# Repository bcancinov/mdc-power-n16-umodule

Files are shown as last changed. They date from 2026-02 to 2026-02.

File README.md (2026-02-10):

# mdc-power-n16-umodule
Modular Detector Controller Power -16V uModule Mezzanine Module

## Overview
12V input to -16V output DC-DC module, 0.5A nominal output, used as one of the `mdc-power-*` bias rails.
Designed for 2 MHz sync operation.
Mezzanine module.

## Power Stage
- Controller: `LTM4651` (uModule)
  - Integrated µModule regulator including controller, MOSFETs, inductor, and support components.
  - EN55022B compliant regulator family (meets Class B EMI limits for conducted and radiated emissions).
  - External sync capability.

## Files
- Schematic: `power_n16_umodule.pdf`

## Board Dimensions
- 44.8 mm x 41.5 mm

## Board Stackup
- 4-layer PCB

## CAD
- Designed using KiCad 9.

## Interface
- Control pins: `EN` (enable) and `PG` / `~PGOOD` (power good).
- Connector: `LSHM-140-04.0-L-DV-A-N-K-TR` (Samtec LSHM series) mezzanine for power and control signals.
  - Common pinout is shared across the 16V, -16V, 6V, and 3.3V variants.
  - Unused output rails are tied to GND on the specific module variant.

## Images
Layout:
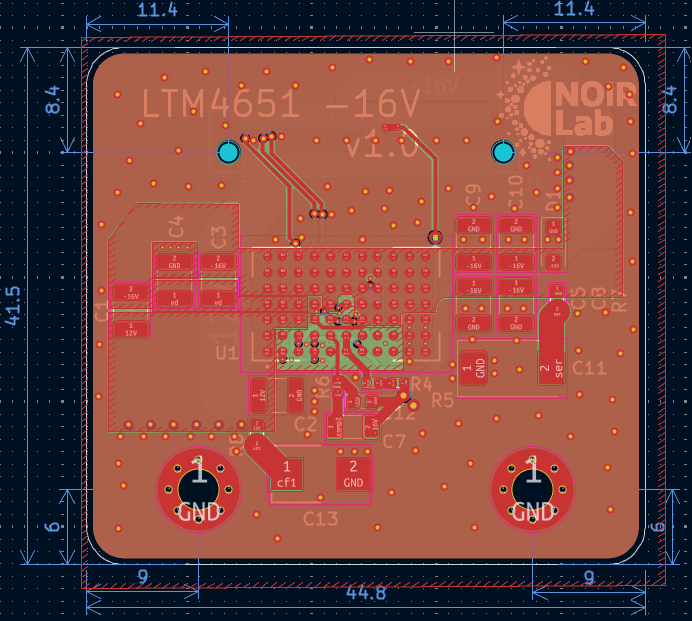
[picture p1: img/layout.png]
Layout


3D view:
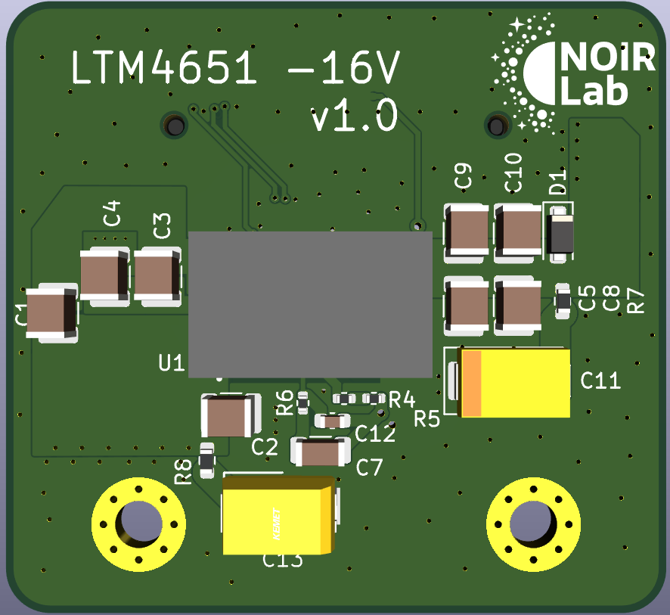
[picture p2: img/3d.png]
3D view


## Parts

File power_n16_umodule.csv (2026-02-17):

Reference | Qty | MPN | M | Description
C1,C2,C3,C4 | 4 | GRM32ER71K475KE14L | Murata | 4.7 µF ±10% 80V Ceramic Capacitor X7R 1210 (3225 Metric)
C5,C8,C9,C10 | 4 | TMK325ABJ476MM-P | TAIYO YUDEN | 47 µF ±20% 25V Ceramic Capacitor X5R 1210 (3225 Metric)
C6 | 1 | GCM21BR71H105KA03L | Murata | 1 µF ±10% 50V Ceramic Capacitor X7R 0805 (2012 Metric)
C7 | 1 | GCM31M5C1H473FA16L | Murata | 0.047 µF ±1% 50V Ceramic Capacitor C0G, NP0 1206 (3216 Metric)
C11 | 1 | T521V226M025ATE040 | KEMET | 22 µF Molded Tantalum Polymer Capacitor 25 V 2917 (7343 Metric) 40mOhm @ 100kHz
C12 | 1 | GCM1885C2A100FA16D | Murata | 10 pF ±1% 100V Ceramic Capacitor C0G, NP0 0603 (1608 Metric)
C13 | 1 | T521X107M025ATE060 | Kemet | 100 µF Molded Tantalum Polymer Capacitor 25 V 2917 (7343 Metric) 60mOhm @ 100kHz
D1 | 1 | CMMSH1-40L TR PBFREE | Central Semiconductor Corp | Diode 40 V 1A Surface Mount SOD-123F
H1,H2,NT1 | 3 |  |  | Mounting Hole with connection,Net tie, 2 pins
J1 | 1 | LSHM-140-04.0-L-DV-A-N-K-TR | Samtec | 80 Position Connector Self Mating, Non-Gendered, Hermaphroditic Surface Mount Gold
R1 | 1 | CRCW040262K0FKED | Vishay | 62 kOhms ±1% 0.063W, 1/16W Chip Resistor 0402 (1005 Metric) Automotive AEC-Q200 Thick Film
R2 | 1 | CRCW0402127KFKEDC | Vishay | 127 kOhms ±1% 0.063W, 1/16W Chip Resistor 0402 (1005 Metric) Thick Film
R3 | 1 | CRCW040268R0FKEDHP | Vishay | 68 Ohms ±1% 0.2W, 1/5W Chip Resistor 0402 (1005 Metric) Automotive AEC-Q200, Pulse Withstanding Thick Film
R4 | 1 | CRCW0402316KFKED | Vishay | 316 kOhms ±1% 0.063W, 1/16W Chip Resistor 0402 (1005 Metric) Automotive AEC-Q200 Thick Film
R5 | 1 | CRCW04024K02FKED | Vishay | 4.02 kOhms ±1% 0.063W, 1/16W Chip Resistor 0402 (1005 Metric) Automotive AEC-Q200 Thick Film
R6 | 1 | CRCW04023K48FKED | Vishay | 3.48 kOhms ±1% 0.1W, 1/10W Chip Resistor 0402 (1005 Metric) Automotive AEC-Q200 Thick Film
R7,R8 | 2 | RCWE0603R500FKEA | Vishay | 500 mOhms ±1% 0.2W, 1/5W Chip Resistor 0603 (1608 Metric) Automotive AEC-Q200, Current Sense, Moisture Resistant Thick Film
U1 | 1 | LTM4651EY#PBF | Analog Devices | Non-Isolated PoL Module DC DC Converter 1 Output -0.5 ~ -26.5V 3.6V - 58V Input

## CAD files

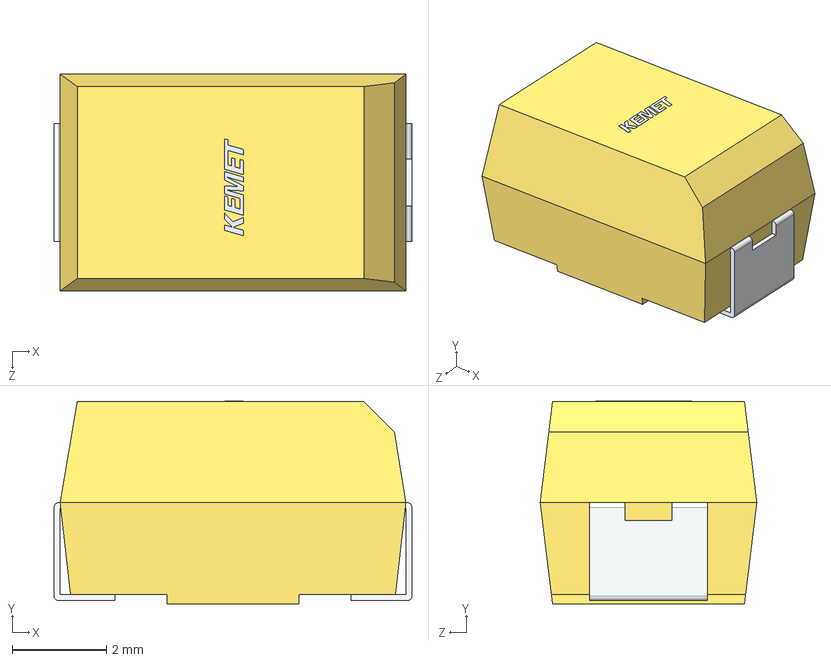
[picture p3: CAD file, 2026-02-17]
step/T521X.step
7.60 x 4.30 x 4.60 mm

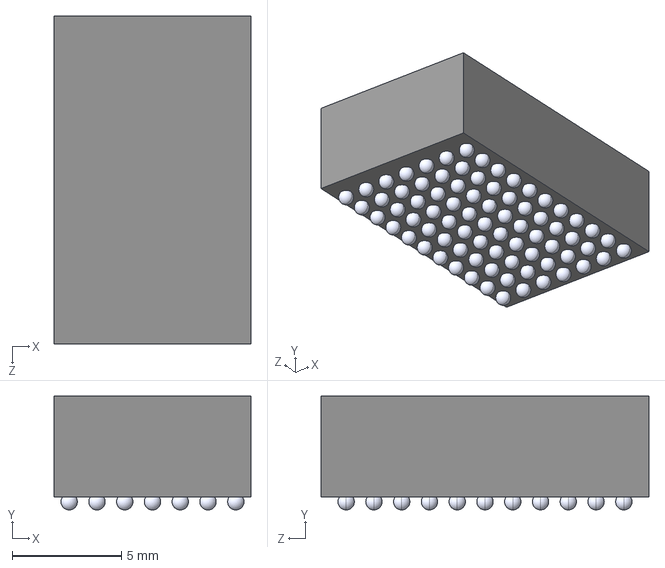
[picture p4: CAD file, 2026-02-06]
step/LTM4651EY_PBF.step
9.00 x 5.21 x 15.0 mm

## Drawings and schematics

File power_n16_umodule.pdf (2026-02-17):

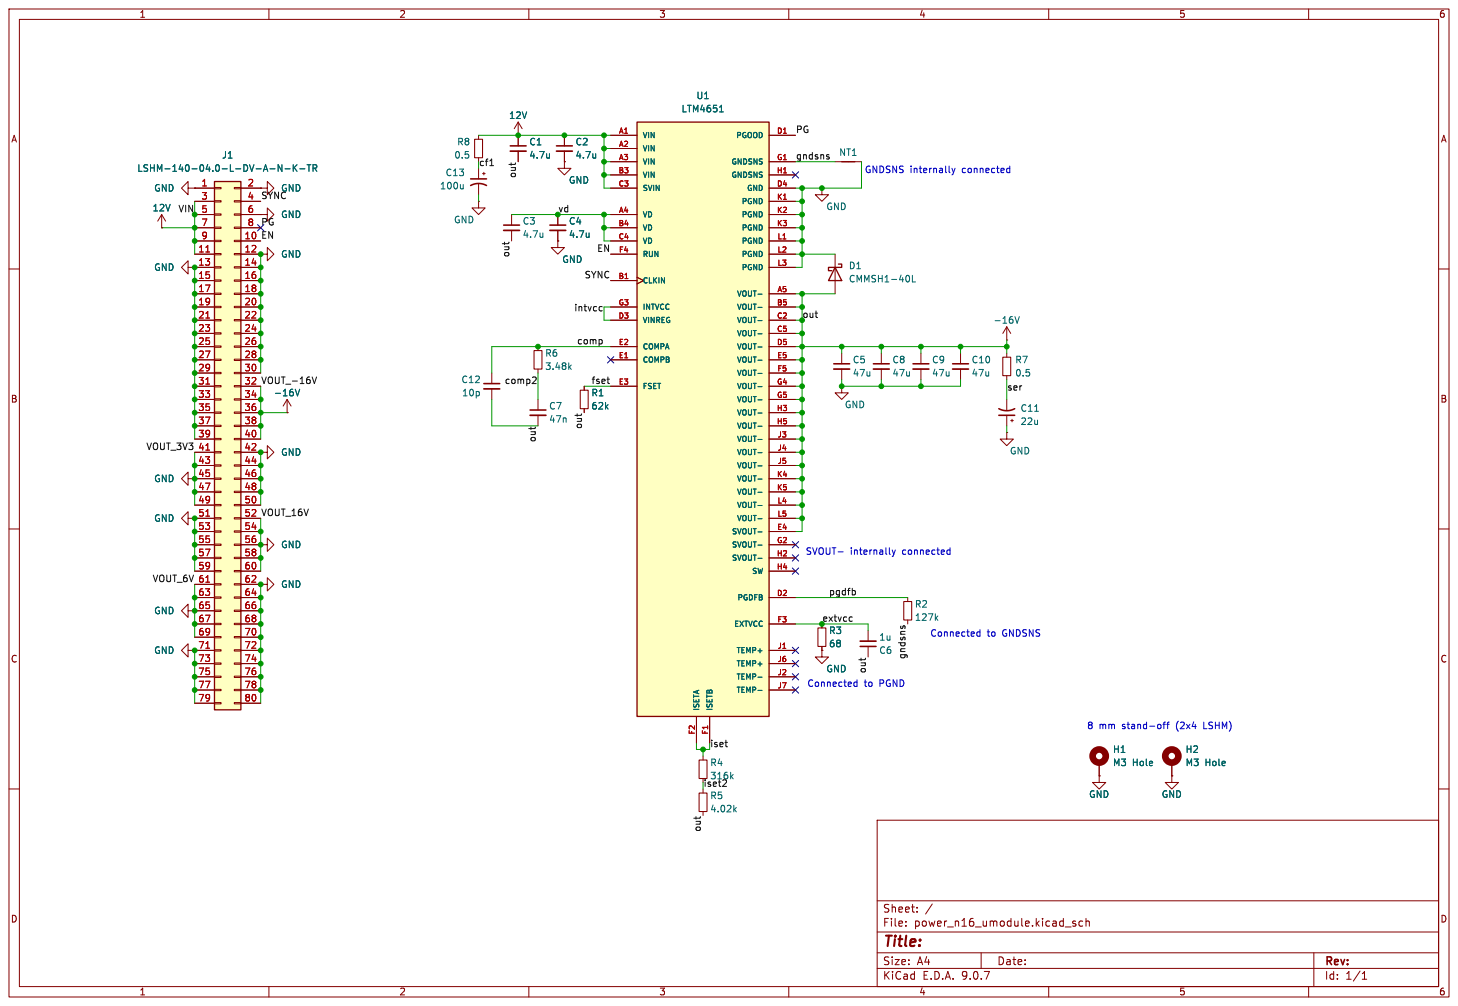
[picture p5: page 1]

LSHM-140-04.0-L-DV-A-N-K-TR GND GND
-16V GND GND
VIN

Id: 1/1 Title: File: power_n16_umodule.kicad_sch Sheet: /

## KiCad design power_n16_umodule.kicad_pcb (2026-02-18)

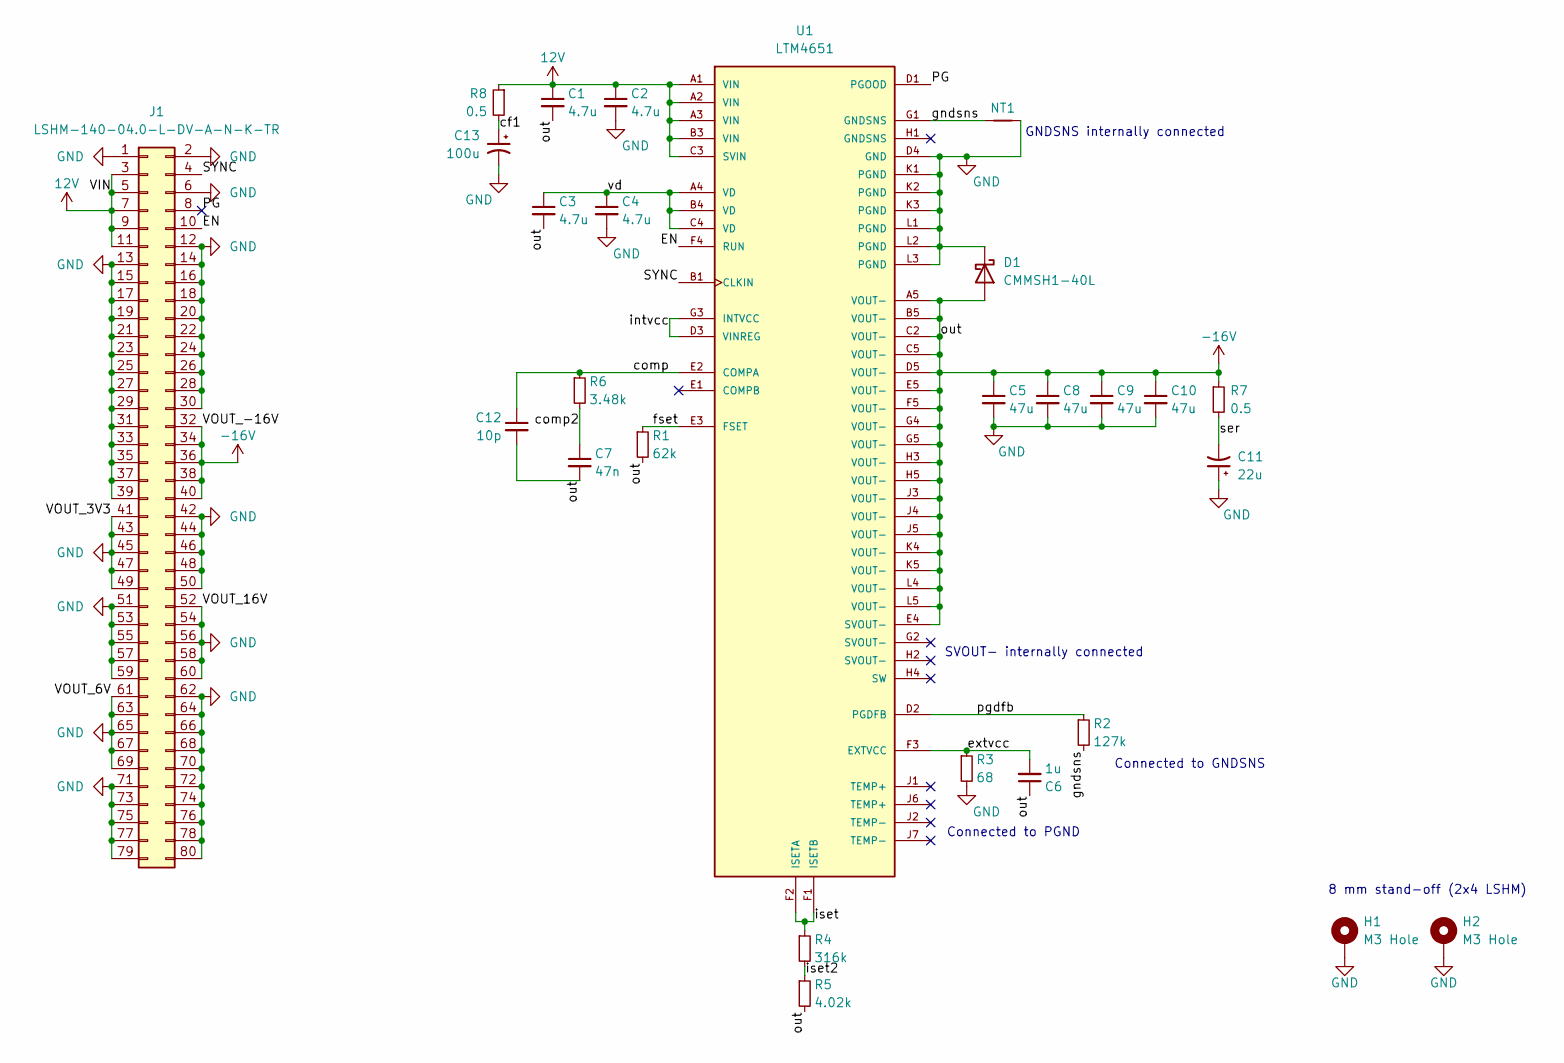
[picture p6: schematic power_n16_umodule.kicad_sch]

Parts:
C1, C2, C3, C4: 4.7u; C_1210_3225Metric; MPN GRM32ER71K475KE14L
C5, C8, C9, C10: 47u; C_1210_3225Metric; MPN TMK325ABJ476MM-P
C6: 1u; C_0805_2012Metric; MPN GCM21BR71H105KA03L
C7: 47n; C_1206_3216Metric; MPN GCM31M5C1H473FA16L
C11: 22u; CP_EIA-7343-20_Kemet-V; MPN T521V226M025ATE040
C12: 10p; C_0603_1608Metric; MPN GCM1885C2A100FA16D
C13: 100u; T521X; MPN T521X107M025ATE060
D1: CMMSH1-40L; D_SOD-123F; MPN CMMSH1-40L TR PBFREE
H1, H2: M3 Hole; MountingHole_3.2mm_M3_Pad_Via
J1: LSHM-140-04.0-L-DV-A-N-K-TR; SAMTEC_LSHM-140-04.0-L-DV-A-N-K-TR; MPN LSHM-140-04.0-L-DV-A-N-K-TR
NT1: NetTie-2_SMD_Pad0.5mm
R1: 62k; R_0402_1005Metric; MPN CRCW040262K0FKED
R2: 127k; R_0402_1005Metric; MPN CRCW0402127KFKEDC
R3: 68; R_0402_1005Metric; MPN CRCW040268R0FKEDHP
R4: 316k; R_0402_1005Metric; MPN CRCW0402316KFKED
R5: 4.02k; R_0402_1005Metric; MPN CRCW04024K02FKED
R6: 3.48k; R_0402_1005Metric; MPN CRCW04023K48FKED
R7, R8: 0.5; R_0603_1608Metric; MPN RCWE0603R500FKEA
U1: LTM4651; MPN LTM4651EY#PBF

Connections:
12V: C1.1, C2.1, J1.3, J1.5, J1.7, J1.9, J1.11, R8.1, U1.A1 (VIN), U1.A2 (VIN), U1.A3 (VIN), U1.B3 (VIN), U1.C3 (SVIN)
-16V: C1.2, C3.2, C5.1, C6.1, C7.2, C8.1, C9.1, C10.1, C12.2, D1.2 (A), J1.32, J1.34, J1.36, J1.38, J1.40, R1.2, R5.2, R7.1, U1.A5 (VOUT-), U1.B5 (VOUT-), U1.C2 (VOUT-), U1.C5 (VOUT-), U1.D5 (VOUT-), U1.E4 (SVOUT-), U1.E5 (VOUT-), U1.F5 (VOUT-), U1.G4 (VOUT-), U1.G5 (VOUT-), U1.H3 (VOUT-), U1.H5 (VOUT-), U1.J3 (VOUT-), U1.J4 (VOUT-), U1.J5 (VOUT-), U1.K4 (VOUT-), U1.K5 (VOUT-), U1.L4 (VOUT-), U1.L5 (VOUT-)
/EN: J1.10, U1.F4 (RUN)
/PG: J1.8, U1.D1 (PGOOD)
/SYNC: J1.4, U1.B1 (CLKIN)
/cf1: C13.1, R8.2
/comp: C12.1, R6.1, U1.E2 (COMPA)
/comp2: C7.1, R6.2
/extvcc: C6.2, R3.1, U1.F3 (EXTVCC)
/fset: R1.1, U1.E3 (FSET)
/gndsns: NT1.1, R2.2, U1.G1 (GNDSNS)
/intvcc: U1.D3 (VINREG), U1.G3 (INTVCC)
/iset: R4.1, U1.F1 (ISETB), U1.F2 (ISETA)
/iset2: R4.2, R5.1
/pgdfb: R2.1, U1.D2 (PGDFB)
/ser: C11.2, R7.2
/vd: C3.1, C4.1, U1.A4 (VD), U1.B4 (VD), U1.C4 (VD)
GND: C2.2, C4.2, C5.2, C8.2, C9.2, C10.2, C11.1, C13.2, D1.1 (K), H1.1, H2.1, J1.1, J1.2, J1.6, J1.12, J1.13, J1.14, J1.15, J1.16, J1.17, J1.18, J1.19, J1.20, J1.21, J1.22, J1.23, J1.24, J1.25, J1.26, J1.27, J1.28, J1.29, J1.30, J1.31, J1.33, J1.35, J1.37, J1.39, J1.41, J1.42, J1.43, J1.44, J1.45, J1.46, J1.47, J1.48, J1.49, J1.50, J1.51, J1.52, J1.53, J1.54, J1.55, J1.56, J1.57, J1.58, J1.59, J1.60, J1.61, J1.62, J1.63, J1.64, J1.65, J1.66, J1.67, J1.68, J1.69, J1.70, J1.71, J1.72, J1.73, J1.74, J1.75, J1.76, J1.77, J1.78, J1.79, J1.80, NT1.2, R3.2, U1.D4 (GND), U1.K1 (PGND), U1.K2 (PGND), U1.K3 (PGND), U1.L1 (PGND), U1.L2 (PGND), U1.L3 (PGND)

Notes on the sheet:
SVOUT- internally connected
8 mm stand-off (2x4 LSHM)
Connected to GNDSNS
GNDSNS internally connected
Connected to PGND

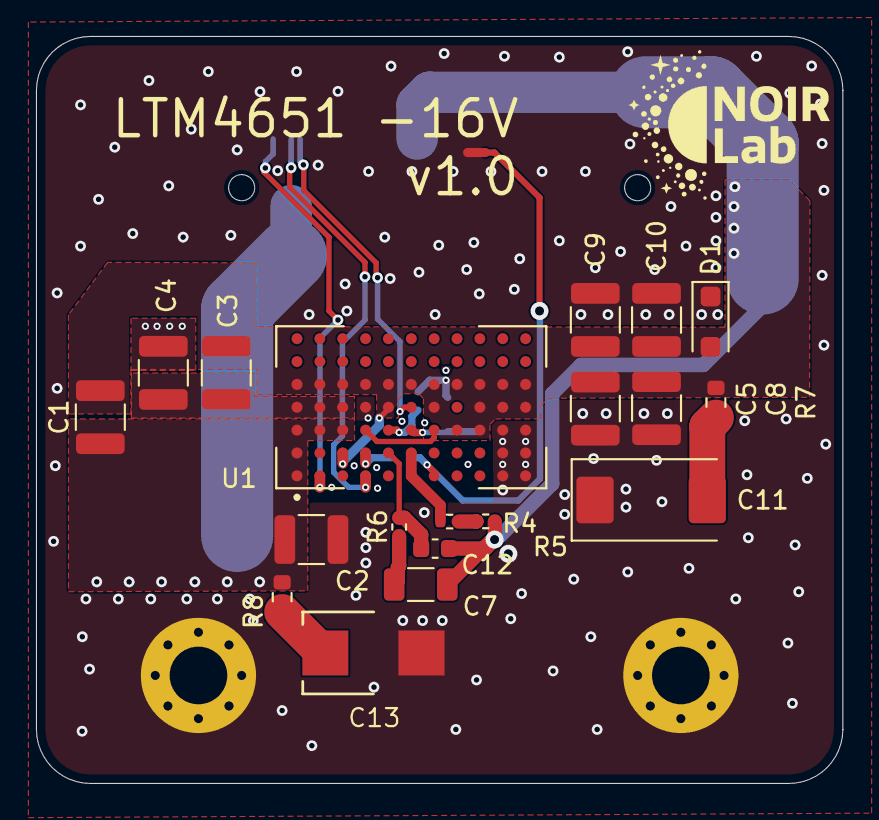
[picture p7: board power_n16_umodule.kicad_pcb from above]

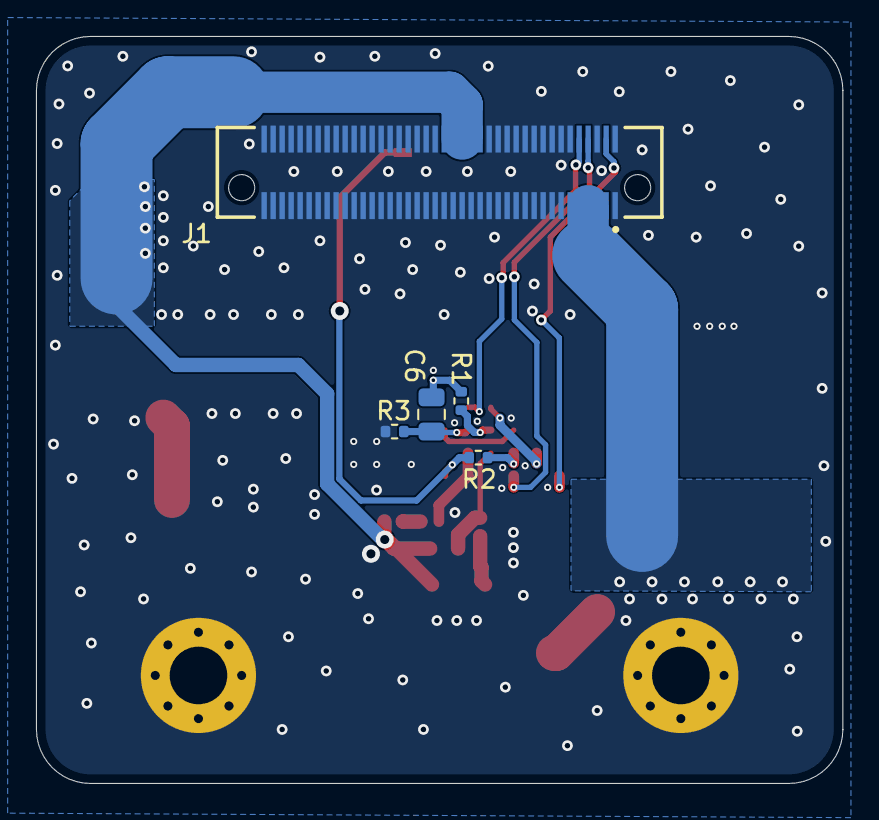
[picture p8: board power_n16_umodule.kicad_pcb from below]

Board: 4 copper layers, 44.8 x 41.5 mm, 27 parts (5 on the bottom side), 18 nets.

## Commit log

2026-02-06 Add BOM
    [power_n16_umodule.csv]
2026-02-17 Add Ferrite Beads
    [T521X.step, power_n16_umodule.csv, power_n16_umodule.kicad_pcb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]
